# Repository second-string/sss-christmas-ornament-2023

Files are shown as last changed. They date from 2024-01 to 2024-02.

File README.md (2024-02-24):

# Berghain PCB Christmas Ornament
Designed by Second String Studios

## Boards
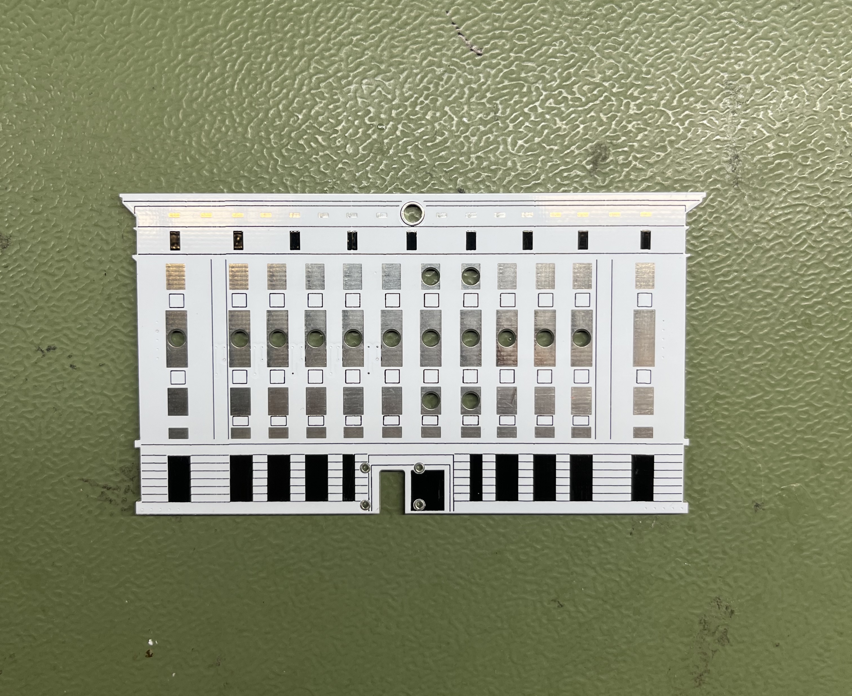
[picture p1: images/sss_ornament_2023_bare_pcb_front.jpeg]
bare pcb front

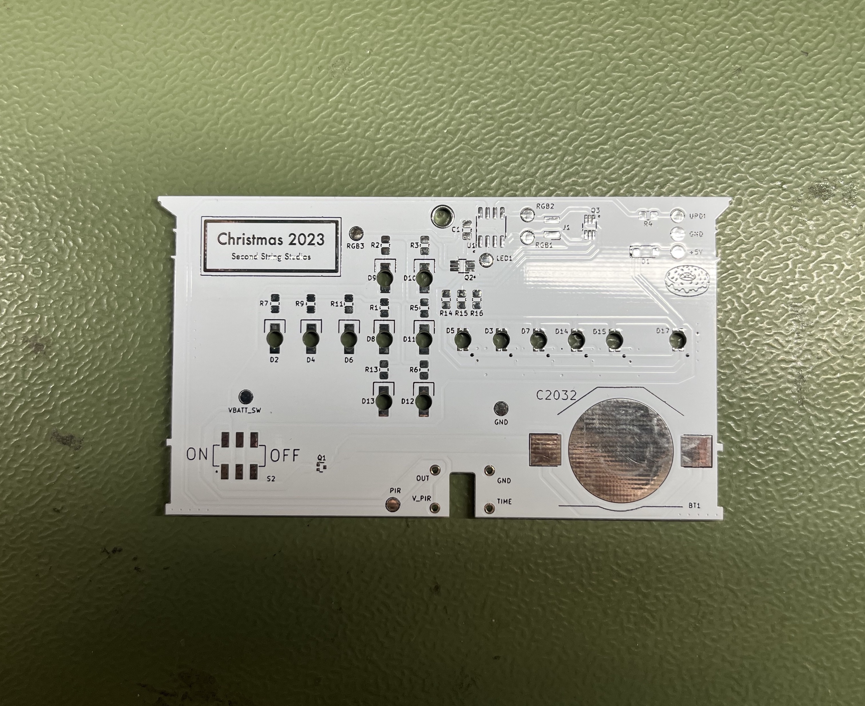
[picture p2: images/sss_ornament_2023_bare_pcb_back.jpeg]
bare pcb back


## Layout
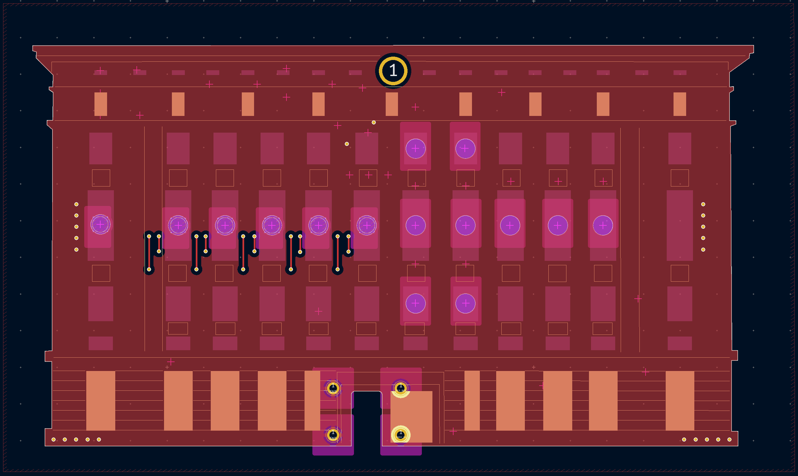
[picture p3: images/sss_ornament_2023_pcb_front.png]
layout front

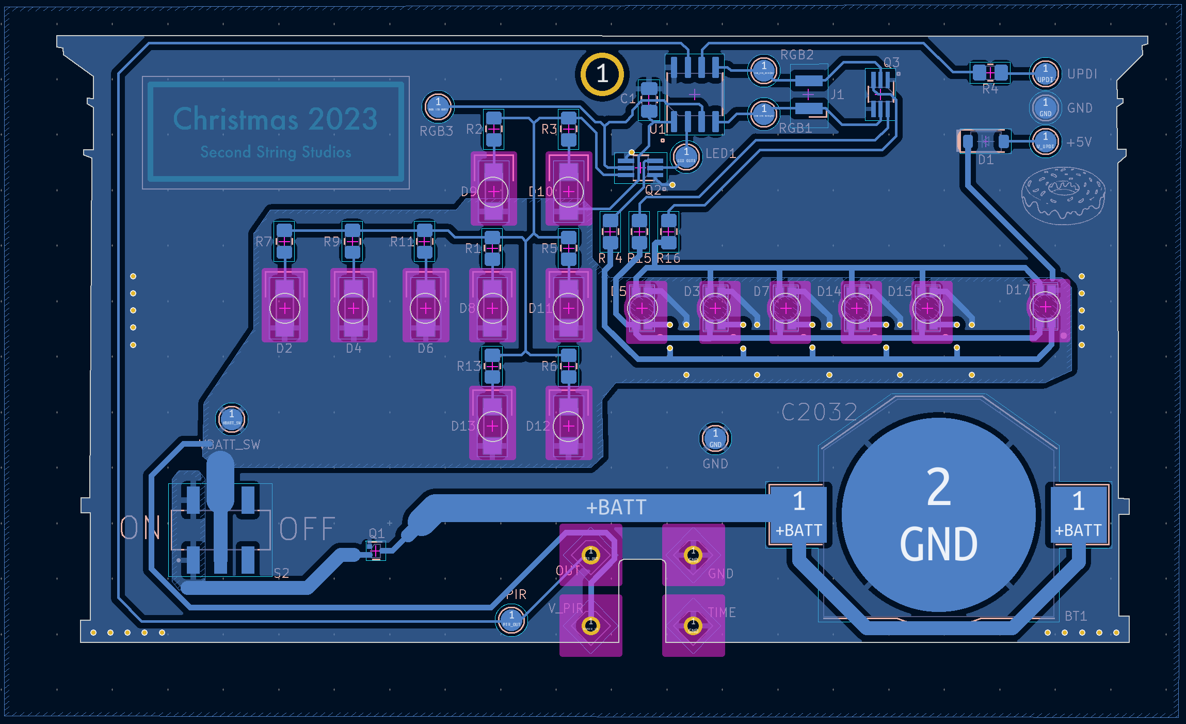
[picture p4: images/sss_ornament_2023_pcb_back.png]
layout back


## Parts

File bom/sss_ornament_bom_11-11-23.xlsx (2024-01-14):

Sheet: Sheet1
Item | Qty | Reference(s) | Value | Footprint | Supplier link
1 | 1 | BT1 | CR2032 | Battery:BatteryHolder_AdamTech_BH-67D-5_1x2032
2 | 1 | C1 | 0.1uF | Capacitor_SMD:C_0805_2012Metric_Pad1.18x1.45mm_HandSolder
3 | 1 | D1 | 1N4148W | Diode_SMD:D_SOD-123
4 | 2 | D2, D4 | LTST-C230KRKT | LTST-C230K:LED_LTST-C230K | https://www.digikey.de/en/products/detail/liteon/LTST-C230KRKT/386857
5 | 6 | D3, D5, D7, D14, D15, D16 | LTST-C230KFKT | LTST-C230K:LED_LTST-C230K | https://www.digikey.de/en/products/detail/liteon/LTST-C230KFKT/2764957
6 | 2 | D6, D8 | LTST-C230KGKT | LTST-C230K:LED_LTST-C230K | https://www.digikey.de/en/products/detail/liteon/LTST-C230KGKT/386855
7 | 5 | D9, D10, D11, D12, D13 | LTST-C230KSKT | LTST-C230K:LED_LTST-C230K | https://www.digikey.de/en/products/detail/liteon/LTST-C230KSKT/386859
8 | 1 | J1 | Conn_01x02_Male | Connector_Harwin:Harwin_M20-89003xx_1x02_P2.54mm_Horizontal
9 | 1 | J2 | PIR_OUT | Connector_PinHeader_2.54mm:PinHeader_1x01_P2.54mm_Vertical
10 | 1 | J3 | GND | Connector_PinHeader_2.54mm:PinHeader_1x01_P2.54mm_Vertical
11 | 1 | J4 | V_PIR | Connector_PinHeader_2.54mm:PinHeader_1x01_P2.54mm_Vertical
12 | 1 | J5 | PIR_TIME | Connector_PinHeader_2.54mm:PinHeader_1x01_P2.54mm_Vertical
13 | 1 | Q1 | Q_PMOS_DGS | Package_TO_SOT_SMD:SOT-723
14 | 15 | R1, R2, R3, R5, R6, R7, R8, R9, R10, R11, R12, R13, R14, R15, R16 | 8.2k | Resistor_SMD:R_0805_2012Metric_Pad1.20x1.40mm_HandSolder
15 | 1 | R4 | 470 | Resistor_SMD:R_0805_2012Metric_Pad1.20x1.40mm_HandSolder
16 | 1 | S2 | JS202011SCQN | SW_JS202011SCQN:SW_JS202011SCQN
17 | 1 | TP1 | V_UPDI | TestPoint:TestPoint_Pad_D2.0mm
18 | 1 | TP2 | UPDI | TestPoint:TestPoint_Pad_D2.0mm
19 | 2 | TP3, TP8 | GND | TestPoint:TestPoint_Pad_D2.0mm
20 | 1 | TP4 | PIR_OUT | TestPoint:TestPoint_Pad_D2.0mm
21 | 1 | TP5 | VBATT_SW | TestPoint:TestPoint_Pad_D2.0mm
22 | 1 | TP6 | LED_OUT1 | TestPoint:TestPoint_Pad_D2.0mm
23 | 1 | TP7 | LED_OUT2 | TestPoint:TestPoint_Pad_D2.0mm
24 | 1 | U1 | ATtiny412-SS | Package_SO:SOIC-8_3.9x4.9mm_P1.27mm

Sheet: Sheet2
Reference | Value | Menge | Footprint | Supplier URL
BT1 | CR2032 | 1 | Battery:BatteryHolder_Keystone_3002_1x2032
C1 | 0.1uF | 1 | Capacitor_SMD:C_0805_2012Metric_Pad1.18x1.45mm_HandSolder
D1 | 1N4148W | 1 | Diode_SMD:D_SOD-123
D2, D4 | LTST-C230KRKT | 2 | LTST-C230K:LED_LTST-C230K
D3, D5, D7, D14, D15, D17 | QLSP15RGB | 6 | QLSP15RGB:QLSP15RGB
D6, D8 | LTST-C230KGKT | 2 | LTST-C230K:LED_LTST-C230K
D9-D13 | LTST-C230KSKT | 5 | LTST-C230K:LED_LTST-C230K
J1 | Conn_01x02_Male | 1 | Connector_Harwin:Harwin_M20-89003xx_1x02_P2.54mm_Horizontal
J2 | PIR_OUT | 1 | Connector_PinHeader_2.54mm:PinHeader_1x01_P2.54mm_Vertical
J3 | GND | 1 | Connector_PinHeader_2.54mm:PinHeader_1x01_P2.54mm_Vertical
J4 | V_PIR | 1 | Connector_PinHeader_2.54mm:PinHeader_1x01_P2.54mm_Vertical
J5 | PIR_TIME | 1 | Connector_PinHeader_2.54mm:PinHeader_1x01_P2.54mm_Vertical
Q1 | Q_PMOS_DGS | 1 | Package_TO_SOT_SMD:SOT-723
Q2, Q3 | PJT138K_R1_00001 | 2 | Package_TO_SOT_SMD:SOT-363_SC-70-6_Handsoldering
R1-R3, R5-R7, R9, R11, R13-R16 | 8.2k | 12 | Resistor_SMD:R_0805_2012Metric_Pad1.20x1.40mm_HandSolder
R4 | 470 | 1 | Resistor_SMD:R_0805_2012Metric_Pad1.20x1.40mm_HandSolder
TP1 | V_UPDI | 1 | TestPoint:TestPoint_Pad_D2.0mm
TP2 | UPDI | 1 | TestPoint:TestPoint_Pad_D2.0mm
TP4 | PIR_OUT | 1 | TestPoint:TestPoint_Pad_D2.0mm
TP5 | VBATT_SW | 1 | TestPoint:TestPoint_Pad_D2.0mm
TP6 | LED_OUT1 | 1 | TestPoint:TestPoint_Pad_D2.0mm
TP7, TP9, TP10 | LED_OUT2 | 3 | TestPoint:TestPoint_Pad_D2.0mm
TP8, TP11 | GND | 2 | TestPoint:TestPoint_Pad_D2.0mm
U1 | ATtiny412-SS | 1 | Package_SO:SOIC-8_3.9x4.9mm_P1.27mm
S2 | JS202011SCQN | 1 | SW_JS202011SCQN

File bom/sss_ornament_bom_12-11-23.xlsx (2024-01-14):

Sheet: BOM
Reference | Value | Menge | Footprint | Supplier URL
BT1 | CR2032 | 1 | Battery:BatteryHolder_Keystone_3002_1x2032 | https://www.digikey.de/en/products/detail/adam-tech/BH-67D-5/13537750
C1 | 0.1uF | 1 | Capacitor_SMD:C_0805_2012Metric_Pad1.18x1.45mm_HandSolder | https://www.digikey.de/en/products/detail/samsung-electro-mechanics/CL21B104KBCNNNC/3886661
D1 | 1N4148W | 1 | Diode_SMD:D_SOD-123 | https://www.digikey.de/en/products/detail/smc-diode-solutions/1N4148W/6022450
D2, D4 | LTST-C230KRKT | 2 | LTST-C230K:LED_LTST-C230K | https://www.digikey.de/en/products/detail/liteon/LTST-C230KRKT/386857
D3, D5, D7, D14, D15, D17 | QLSP15RGB | 6 | QLSP15RGB:QLSP15RGB | https://www.digikey.de/en/products/detail/quelighting-corp/QLSP15RGB/15848697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
D6, D8 | LTST-C230KGKT | 2 | LTST-C230K:LED_LTST-C230K | https://www.digikey.de/en/products/detail/liteon/LTST-C230KGKT/386855
D9-D13 | LTST-C230KSKT | 5 | LTST-C230K:LED_LTST-C230K | https://www.digikey.de/en/products/detail/liteon/LTST-C230KSKT/386859
Q1 | Q_PMOS_DGS | 1 | Package_TO_SOT_SMD:SOT-723 | https://www.digikey.de/en/products/detail/toshiba-semiconductor-and-storage/SSM3J35AMFV-L3F/8543433
Q2, Q3 | PJT138K_R1_00001 | 2 | Package_TO_SOT_SMD:SOT-363_SC-70-6_Handsoldering | https://www.digikey.de/en/products/detail/panjit-international-inc/PJT138K-R1-00001/15800181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
R1-R3, R5-R7, R9, R11, R13-R16 | 3.3k | 12 | Resistor_SMD:R_0805_2012Metric_Pad1.20x1.40mm_HandSolder | https://www.digikey.de/en/products/detail/yageo/RC0805FR-078K2L/728147
R4 | 470 | 1 | Resistor_SMD:R_0805_2012Metric_Pad1.20x1.40mm_HandSolder | https://www.digikey.de/en/products/detail/yageo/RC0805JR-07470RL/728333
U1 | ATtiny412-SS | 1 | Package_SO:SOIC-8_3.9x4.9mm_P1.27mm | https://www.digikey.de/en/products/detail/microchip-technology/ATTINY412-SSN/9947540
S2 | JS202011SCQN | 1 | SW_JS202011SCQN | https://www.digikey.de/en/products/detail/c-k/JS202011SCQN/2094299
XX | 1528-4667-ND | 1 | 4 through-holes manually placed | https://www.digikey.de/en/products/detail/adafruit-industries-llc/4667/13175529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

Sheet: Existing stock
Value | Menge | Footprint | Existing quantity
CR2032 | 1 | Battery:BatteryHolder_Keystone_3002_1x2032 | 1
0.1uF | 1 | Capacitor_SMD:C_0805_2012Metric_Pad1.18x1.45mm_HandSolder | 10
1N4148W | 1 | Diode_SMD:D_SOD-123 | 1
LTST-C230KRKT | 2 | LTST-C230K:LED_LTST-C230K | 0
QLSP15RGB | 6 | QLSP15RGB:QLSP15RGB | 0
LTST-C230KGKT | 2 | LTST-C230K:LED_LTST-C230K | 0
LTST-C230KSKT | 5 | LTST-C230K:LED_LTST-C230K | 0
Q_PMOS_DGS | 1 | Package_TO_SOT_SMD:SOT-723 | 1
PJT138K_R1_00001 | 2 | Package_TO_SOT_SMD:SOT-363_SC-70-6_Handsoldering | 0
3.3k | 12 | Resistor_SMD:R_0805_2012Metric_Pad1.20x1.40mm_HandSolder | 19
470 | 1 | Resistor_SMD:R_0805_2012Metric_Pad1.20x1.40mm_HandSolder | 1
ATtiny412-SS | 1 | Package_SO:SOIC-8_3.9x4.9mm_P1.27mm | 9
JS202011SCQN | 1 | SW_JS202011SCQN | 1
1528-4667-ND | 1 | 4 through-holes manually placed | 0
0 | 0 | 0

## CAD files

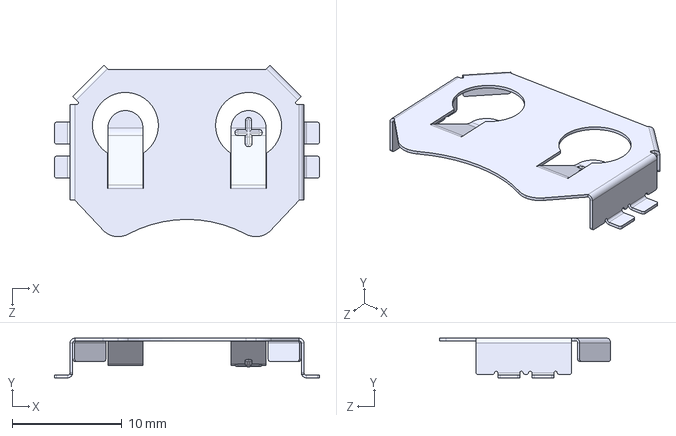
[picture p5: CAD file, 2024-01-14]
symbols_and_footprints/BH-67D-5/BH-67D-5.step
24.1 x 3.60 x 15.6 mm

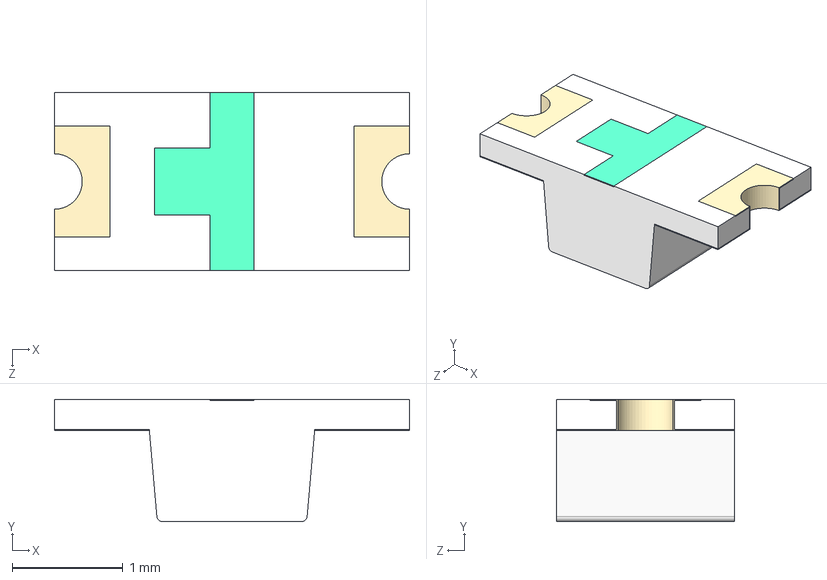
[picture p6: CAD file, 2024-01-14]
symbols_and_footprints/LTST-C230K/LTST-C230K.step
3.20 x 1.10 x 1.60 mm

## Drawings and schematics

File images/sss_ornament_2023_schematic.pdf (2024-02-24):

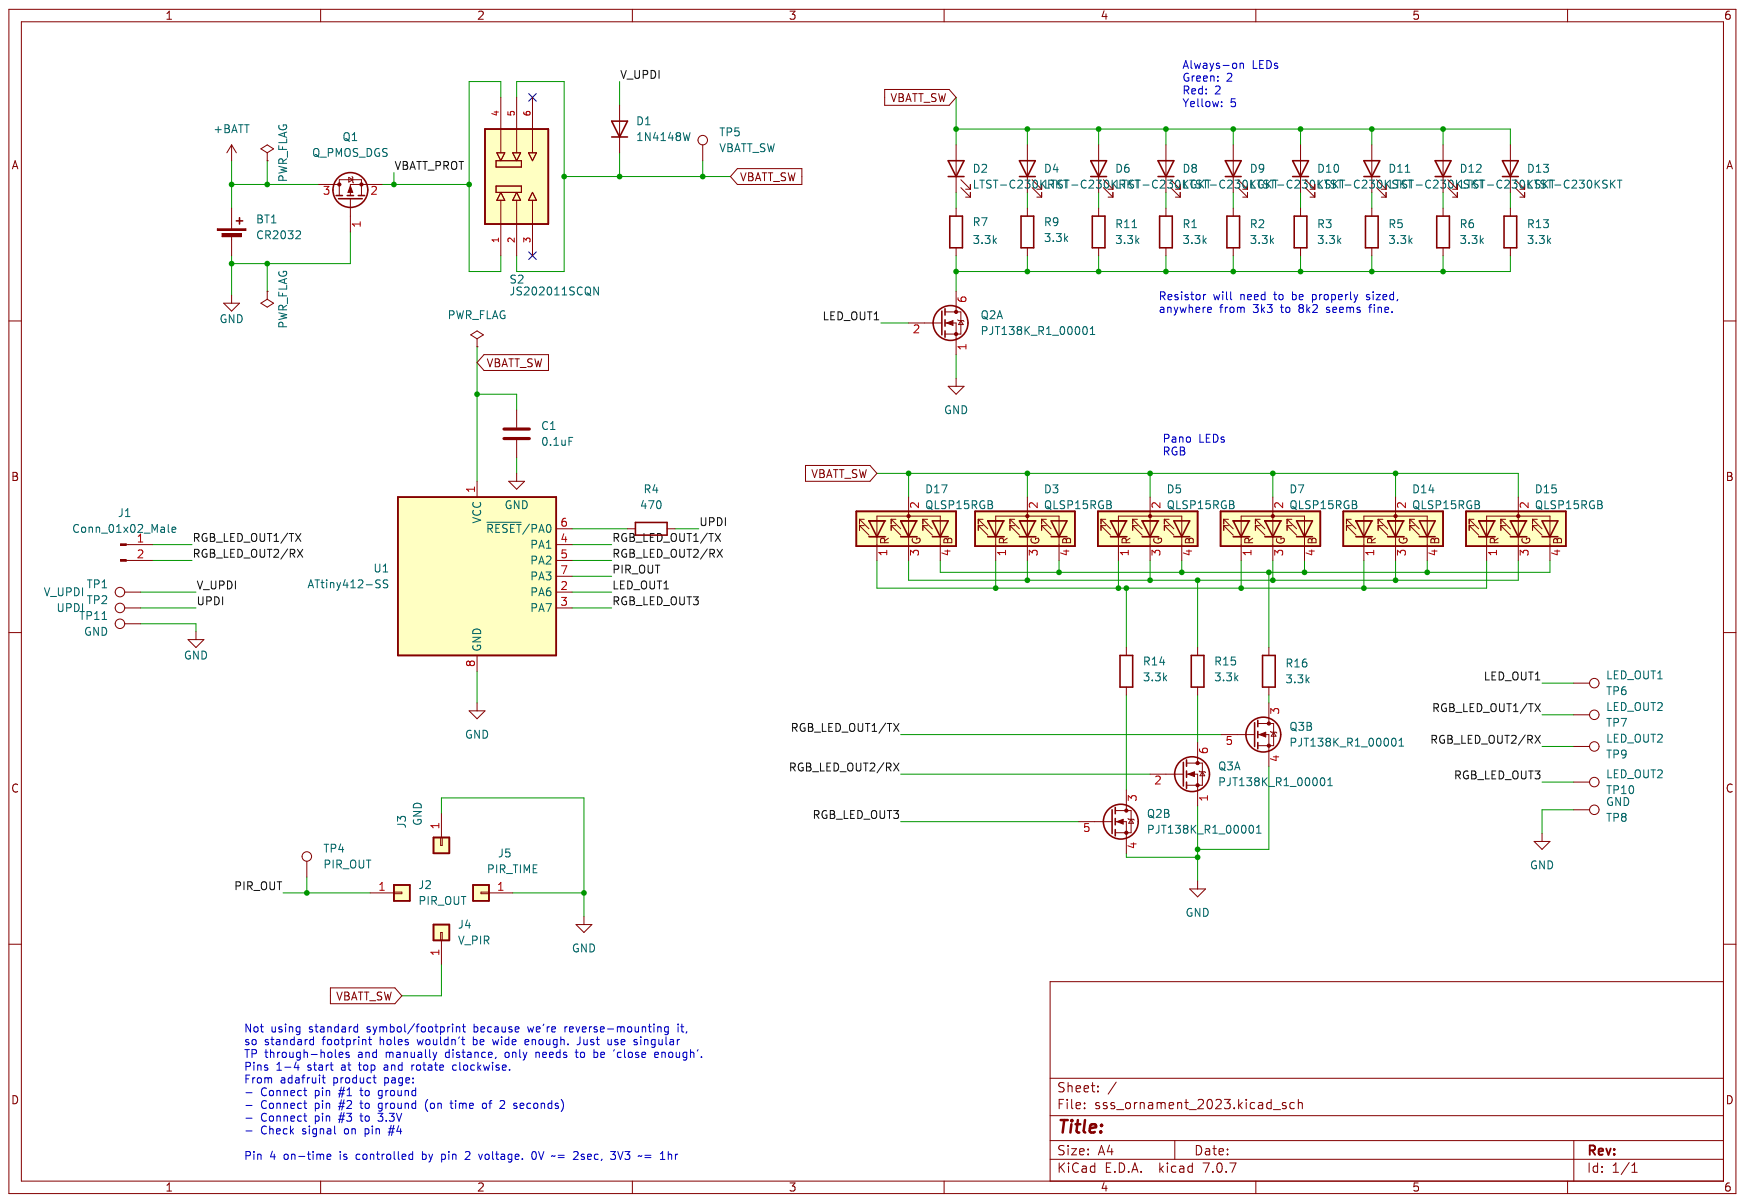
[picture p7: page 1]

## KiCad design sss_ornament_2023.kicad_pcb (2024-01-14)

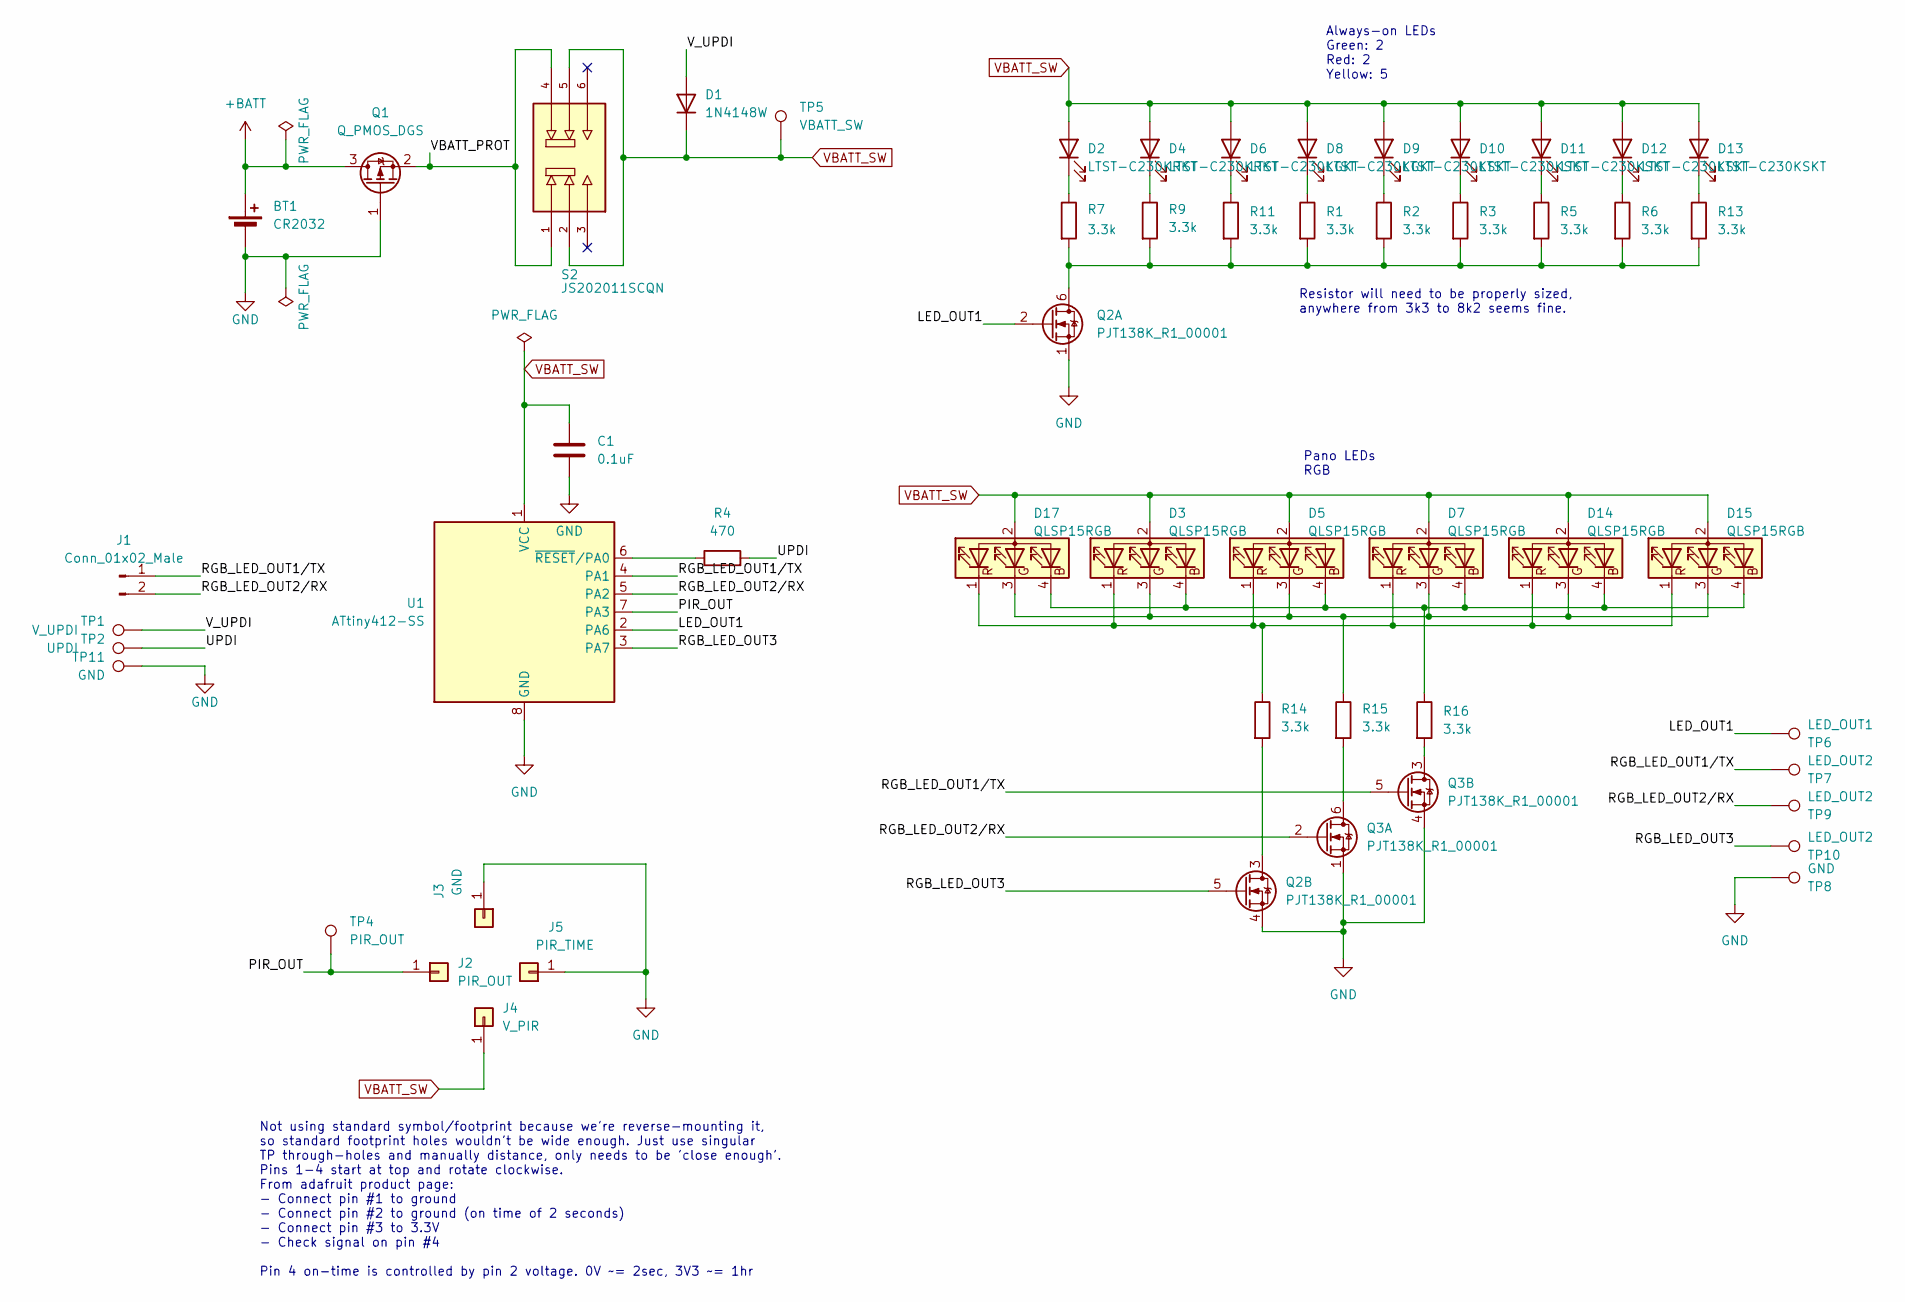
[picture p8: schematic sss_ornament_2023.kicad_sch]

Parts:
BT1: CR2032; BatteryHolder_Keystone_3002_1x2032
C1: 0.1uF; C_0805_2012Metric_Pad1.18x1.45mm_HandSolder
D1: 1N4148W; D_SOD-123
D2, D4: LTST-C230KRKT; LED_LTST-C230K
D3, D5, D7, D14, D15, D17: QLSP15RGB
D6, D8: LTST-C230KGKT; LED_LTST-C230K
D9, D10, D11, D12, D13: LTST-C230KSKT; LED_LTST-C230K
J1: Conn_01x02_Male; Harwin_M20-89003xx_1x02_P2.54mm_Horizontal
J2: PIR_OUT; PinHeader_1x01_P2.54mm_Vertical
J3: GND; PinHeader_1x01_P2.54mm_Vertical
J4: V_PIR; PinHeader_1x01_P2.54mm_Vertical
J5: PIR_TIME; PinHeader_1x01_P2.54mm_Vertical
Q1: Q_PMOS_DGS; SOT-723
Q2, Q3: PJT138K_R1_00001; SOT-363_SC-70-6_Handsoldering
R1, R2, R3, R5, R6, R7, R9, R11, R13, R14, R15, R16: 3.3k; R_0805_2012Metric_Pad1.20x1.40mm_HandSolder
R4: 470; R_0805_2012Metric_Pad1.20x1.40mm_HandSolder
S2: JS202011SCQN; SW_JS202011SCQN
TP1: V_UPDI; TestPoint_Pad_D2.0mm
TP2: UPDI; TestPoint_Pad_D2.0mm
TP4: PIR_OUT; TestPoint_Pad_D2.0mm
TP5: VBATT_SW; TestPoint_Pad_D2.0mm
TP6: LED_OUT1; TestPoint_Pad_D2.0mm
TP7, TP9, TP10: LED_OUT2; TestPoint_Pad_D2.0mm
TP8, TP11: GND; TestPoint_Pad_D2.0mm
U1: ATtiny412-SS; SOIC-8_3.9x4.9mm_P1.27mm

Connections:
+BATT: BT1.1 (+), Q1.3 (D)
/LED_OUT1: Q2.2 (G), TP6.1, U1.2 (PA6)
/PIR_OUT: J2.1, TP4.1, U1.7 (PA3)
/RGB_LED_OUT1/TX: J1.1, Q3.5 (G), TP7.1, U1.4 (PA1)
/RGB_LED_OUT2/RX: J1.2, Q3.2 (G), TP9.1, U1.5 (PA2)
/RGB_LED_OUT3: Q2.5 (G), TP10.1, U1.3 (PA7)
/UPDI: R4.2, TP2.1
/VBATT_PROT: Q1.2 (S), S2.1, S2.4
/V_UPDI: D1.2 (A), TP1.1
GND: BT1.2 (-), C1.2, J3.1, J5.1, Q1.1 (G), Q2.1 (S), Q2.4 (S), Q3.1 (S), Q3.4 (S), TP8.1, TP11.1, U1.8 (GND)
unnamed: D2.1 (K), R7.1
unnamed: D4.1 (K), R9.1
unnamed: D6.1 (K), R11.1
unnamed: D8.1 (K), R1.1
unnamed: D9.1 (K), R2.1
unnamed: D10.1 (K), R3.1
unnamed: D11.1 (K), R5.1
unnamed: D12.1 (K), R6.1
unnamed: D13.1 (K), R13.1
unnamed: D3.4 (BK), D5.4 (BK), D7.4 (BK), D14.4 (BK), D15.4 (BK), D17.4 (BK), R16.1
unnamed: D3.3 (GK), D5.3 (GK), D7.3 (GK), D14.3 (GK), D15.3 (GK), D17.3 (GK), R15.1
unnamed: D3.1 (RK), D5.1 (RK), D7.1 (RK), D14.1 (RK), D15.1 (RK), D17.1 (RK), R14.1
unnamed: Q2.6 (D), R1.2, R2.2, R3.2, R5.2, R6.2, R7.2, R9.2, R11.2, R13.2
unnamed: Q2.3 (D), R14.2
unnamed: Q3.6 (D), R15.2
unnamed: Q3.3 (D), R16.2
unnamed: R4.1, U1.6 (~RESET/PA0)
VBATT_SW: C1.1, D1.1 (K), D2.2 (A), D3.2 (A), D4.2 (A), D5.2 (A), D6.2 (A), D7.2 (A), D8.2 (A), D9.2 (A), D10.2 (A), D11.2 (A), D12.2 (A), D13.2 (A), D14.2 (A), D15.2 (A), D17.2 (A), J4.1, S2.2, S2.5, TP5.1, U1.1 (VCC)

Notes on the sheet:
Resistor will need to be properly sized, anywhere from 3k3 to 8k2 seems fine.
Pano LEDs RGB
Not using standard symbol/footprint because we're reverse-mounting it, so standard footprint holes wouldn't be wide enough. Just use singular TP through-holes and manually distance, only needs to be 'close enough'. Pins 1-4 start at top and rotate clockwise. From adafruit product page: - Connect pi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
Always-on LEDs Green: 2 Red: 2 Yellow: 5

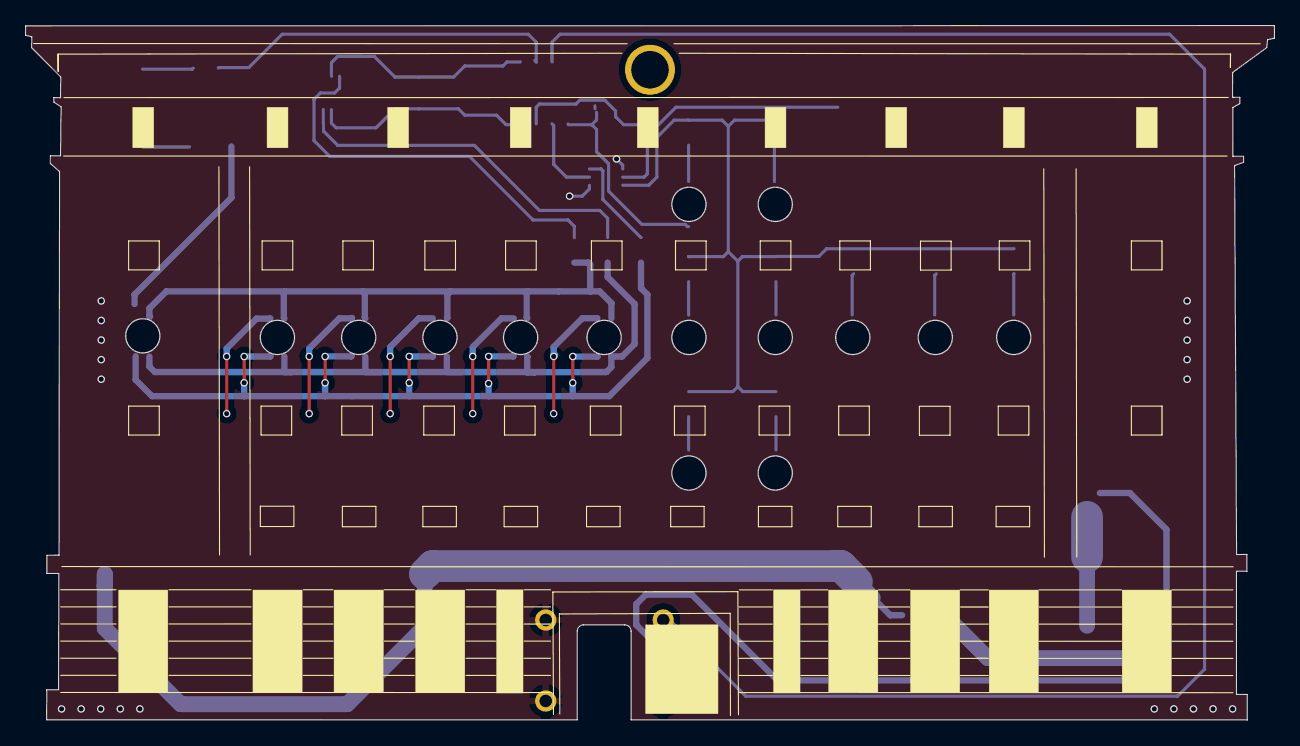
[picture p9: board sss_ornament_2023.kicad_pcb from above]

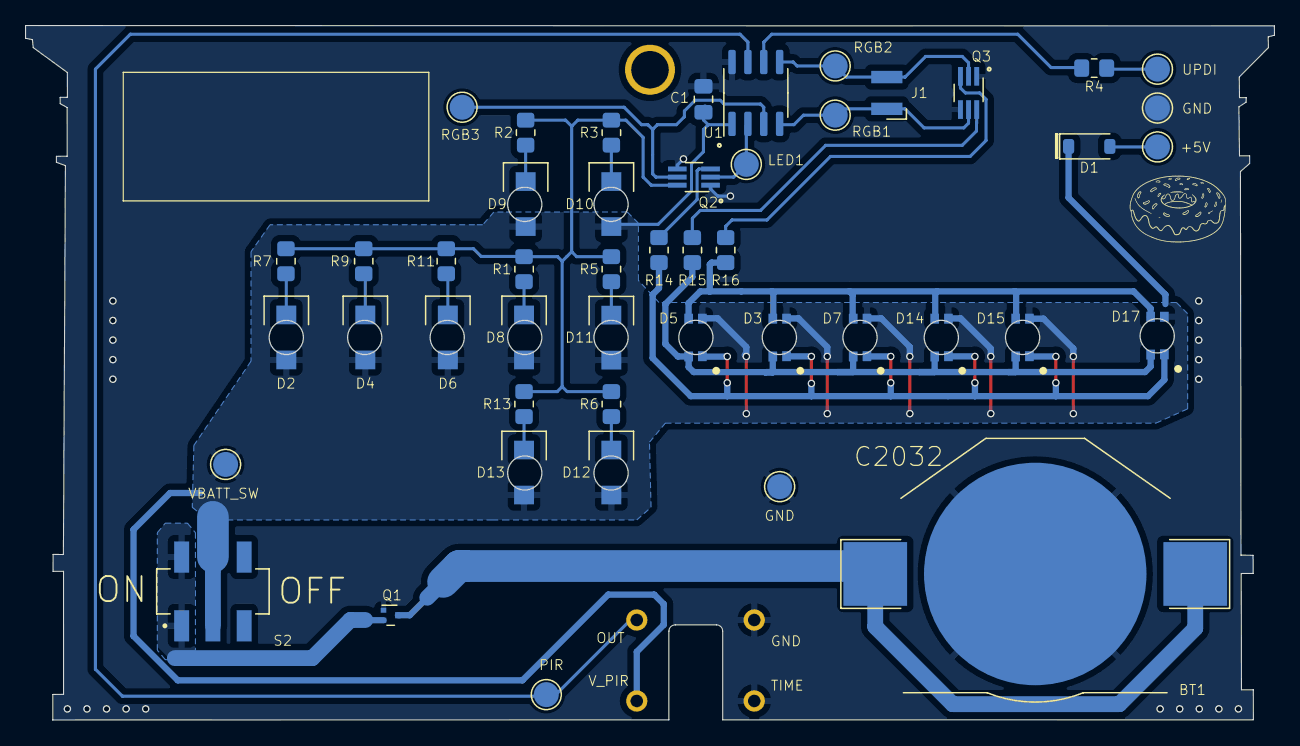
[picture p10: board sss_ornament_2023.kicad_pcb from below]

Board: 2 copper layers, 99.9 x 55.5 mm, 51 parts (51 on the bottom side), 28 nets.

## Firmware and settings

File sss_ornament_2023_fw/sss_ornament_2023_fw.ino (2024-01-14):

#include <avr/sleep.h>

#define PANO_LED_R_PIN PIN_PA7
#define PANO_LED_G_PIN PIN_PA2
#define PANO_LED_B_PIN PIN_PA1
#define HOUSE_LED_PIN PIN_PA6
#define PIR_IN PIN_PA3

/*
 * Calling it duty cycle but it's the 0-255 value used for analogWrite PWM
 */
#define PANO_LED_DUTY_CYCLE (70)

/*
 * Value between 0 (fully off) and 0xFFF (fully on)
 * Set for house LEDs manually by finding a balance between bright enough to look good, while dim enough to not waste a ton of power since they're always on while awake
 */
#define HOUSE_LED_CMPCLR (0x0FF)

#define SLEEP_TIMEOUT_MIN (15)
#define SLEEP_TIMEOUT_MS (1000UL * 60 * SLEEP_TIMEOUT_MIN)

#if F_CPU != 1000000
#error Must set clock to 1MHz and must burn bootloader for 1MHz operation! PWM for pano LEDs and the delay() timing is fucky with 20MHz clock when we use both TCA (analogWrite) and TCD
#endif

typedef enum {
  PANO_COLOR_RED,
  PANO_COLOR_GREEN,
  PANO_COLOR_BLUE,
  PANO_COLOR_BROWN,
  PANO_COLOR_CYAN,
  PANO_COLOR_YELLOW,

  PANO_COLOR_COUNT,
} pano_color_t;

volatile uint32_t start_ms;
pano_color_t current_pano_color;

/*
 * PIR ISR to reset timeout start_ms  
 */
ISR(PORTA_PORT_vect) {
  PORTA.INTFLAGS = 0xFF;

  // Refresh start time every time PIR triggers. millis doesn't increment in an ISR but we don't
  // care, just refresh to the most recent time. It's also fast enough and ISR safe to do here.
  start_ms = millis();
}

/*
 * Write specified 0-255 duty cycle to correct RGB pins depending on color
 */
void pano_led_write(pano_color_t color, uint8_t duty_cycle) {
    switch (color) {
      case PANO_COLOR_RED:
        analogWrite(PANO_LED_R_PIN, duty_cycle);
        digitalWrite(PANO_LED_G_PIN, LOW);
        digitalWrite(PANO_LED_B_PIN, LOW);
        break;
      case PANO_COLOR_GREEN:
        analogWrite(PANO_LED_G_PIN, duty_cycle);
        digitalWrite(PANO_LED_R_PIN, LOW);
        digitalWrite(PANO_LED_B_PIN, LOW);
        break;
      case PANO_COLOR_BLUE:
        analogWrite(PANO_LED_B_PIN, duty_cycle);
        digitalWrite(PANO_LED_R_PIN, LOW);
        digitalWrite(PANO_LED_G_PIN, LOW);
        break;
      case PANO_COLOR_BROWN:
        analogWrite(PANO_LED_R_PIN, duty_cycle);
        analogWrite(PANO_LED_G_PIN, duty_cycle);
        digitalWrite(PANO_LED_B_PIN, LOW);
        break;
      case PANO_COLOR_CYAN:
        analogWrite(PANO_LED_G_PIN, duty_cycle);
        analogWrite(PANO_LED_B_PIN, duty_cycle);
        digitalWrite(PANO_LED_R_PIN, LOW);
        break;
      case PANO_COLOR_YELLOW:
        analogWrite(PANO_LED_R_PIN, duty_cycle);
        analogWrite(PANO_LED_B_PIN, duty_cycle);
        digitalWrite(PANO_LED_G_PIN, LOW);
        break;
       default:
        digitalWrite(PANO_LED_R_PIN, LOW);
        digitalWrite(PANO_LED_G_PIN, LOW);
        digitalWrite(PANO_LED_B_PIN, LOW);
    }
}

/*
 * Fade in / out in specified timeframes
 */
void pano_led_pulse(pano_color_t color, uint32_t on_duration_ms, uint32_t off_duration_ms) {
  int step_delay_ms = 10;
  
  int steps = on_duration_ms / step_delay_ms;
  int duty_increment = PANO_LED_DUTY_CYCLE / steps;
  for (int new_duty = 0; new_duty <= PANO_LED_DUTY_CYCLE; new_duty += duty_increment) {
    pano_led_write(color, new_duty);
    delay(step_delay_ms);
  }

  steps = off_duration_ms / step_delay_ms;
  duty_increment = PANO_LED_DUTY_CYCLE / steps;
  for (int new_duty = PANO_LED_DUTY_CYCLE; new_duty >= 0; new_duty -= duty_increment) {
    pano_led_write(color, new_duty);
    delay(step_delay_ms);
  }
}

void deep_sleep() {
  // Turn off all LEDs before sleeping
  digitalWrite(PANO_LED_R_PIN, LOW);
  digitalWrite(PANO_LED_G_PIN, LOW);
  digitalWrite(PANO_LED_B_PIN, LOW);
  digitalWrite(HOUSE_LED_PIN, LOW);
  
  sleep_enable();
  set_sleep_mode(SLEEP_MODE_STANDBY);
  sleep_cpu();

  // Disable once (if) we wake back up and refresh sleep timer
  start_ms = millis();
  sleep_disable();
}

void house_led_pwm_init(void) {
    // Enable-protected reg must have 0 written to enable bit before any other bits can be changed, and it defaults to
    // enabled on startup
    TCD0.CTRLA &= ~TCD_ENABLE_bm;

    // Don't need overlapping PWM signals so just do oneramp
    TCD0.CTRLB = TCD_WGMODE_ONERAMP_gc;

    // Disable all input control
    TCD0.INPUTCTRLA = TCD_INPUTMODE_NONE_gc;

    // Set/clear values to create desired duty cycle. Don't care about CMPB (outputs on PA7) at all so leave it off
    TCD0.CMPASET = 0x000;
    TCD0.CMPACLR = HOUSE_LED_CMPCLR;
    
    // System 1MHz clock w/ DIV4 standard prescaler but no synchronization prescaler (I think they multiply together, not add).
    // Must be done as last operation before starting timer with ENABLE bit
    // NOTE :: DEFAULT TIMER FOR MILLIS/MICROS FUNCTIONS ON 1-SERIES ATTINIES IS TCD. I think this still works with it set as the default,
    // but if not, try switching it to TCB0.
    TCD0.CTRLA = TCD_CLKSEL_SYSCLK_gc | TCD_CNTPRES_DIV4_gc | TCD_SYNCPRES_DIV1_gc;
}

void house_led_pwm_start(void) {
  // Turn off output override (because we want pwm to run it duh)
  TCD0.CTRLC &= ~TCD_CMPOVR_bm;
    
  // Enable WOA (PA6) but not and WOB/C/D (PA7/?/?). Since FAULTCTRL reg is write protected we need to make it editable in
  // CCP reg. Must be done in start func because we can't take over output pins in stop func unless we disable them in FAULTCTRL.
  CPU_CCP        = CCP_IOREG_gc;
  TCD0.FAULTCTRL = TCD_CMPAEN_bm;
  
  while (!(TCD0.STATUS & TCD_ENRDY_bm)) {
      ;
  }

  TCD0.CTRLA |= TCD_ENABLE_bm;
}

/*
 * Must be called every time TCD0.CMPASET or TCD0.CMPACLR are updated for them to take effect if they're changed while PWM running.
 */
void house_led_pwm_sync(void) {
    TCD0.CTRLE = TCD_SYNCEOC_bm;
}


void setup() {
  pinMode(PANO_LED_R_PIN, OUTPUT);
  pinMode(PANO_LED_G_PIN, OUTPUT);
  pinMode(PANO_LED_B_PIN, OUTPUT);
  pinMode(HOUSE_LED_PIN, OUTPUT);

  house_led_pwm_init();
  house_led_pwm_start();

  current_pano_color = PANO_COLOR_RED;

  // Set up interrupt on PIR pin. Must be BOTHEDGES or LEVEL since we're using a partially-async pin. If using PA2
  // or PA6 (fully async), can wake from deep sleep with any trigger.
  PORTA.PIN3CTRL = (PORTA.PIN3CTRL & ~PORT_ISC_gm) | PORT_ISC_BOTHEDGES_gc | PORT_PULLUPEN_bm;
  
  sei();
}

void loop() {
//   If we've reached timeout with nothing, that means either no movement or constant movement for the timeout period.
//   If the PIR pin is still high, that means it's continuously reported movement, so just refresh the timeout time. If
//   it's low, then the timeout has actually elapsed with no trigger, so sleep.
  if ((millis() - start_ms) > SLEEP_TIMEOUT_MS) {
    if (digitalRead(PIR_IN) == LOW) {
      deep_sleep();
    } else {
      start_ms = millis();
    }
  }

// 150BPM I think...
  pano_led_pulse(current_pano_color, 200, 200);
  pano_led_pulse(current_pano_color, 200, 200);
  pano_led_pulse(current_pano_color, 200, 200);

  pano_led_pulse(current_pano_color, 100, 100);
  pano_led_pulse(current_pano_color, 100, 100);

  current_pano_color = (pano_color_t)((uint8_t)current_pano_color + 1);
  if (current_pano_color == PANO_COLOR_COUNT) {
    current_pano_color = PANO_COLOR_RED;
  }
}

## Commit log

2023-11-11 Initial commit of 2023 project skeleton kicad project. Schematic has previous year's design imported with no changes as base to build upon similar motion-activated-LED design.
    [sss_ornament_2023.kicad_pcb, sss_ornament_2023.kicad_sch]
2024-01-14 Completed 2023 ornament kicad project and all necessary bom/gerber/datasheet/document data
    [BH-67D-5.step, LTST-C230K.step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]
2024-01-14 Completed 2023 ornament firmware for attiny412 flashed over UPDI using megaTinyCore through arduino framework
2024-02-24 add kicad lock files to gitignore
